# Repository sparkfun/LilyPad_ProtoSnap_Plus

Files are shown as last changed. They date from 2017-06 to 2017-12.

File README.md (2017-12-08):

SparkFun LilyPad ProtoSnap Plus
========================================

<table class="table table-hover table-striped table-bordered">
  <tr>
   <td><a href="https://www.sparkfun.com/products/14346"><div align="center">LilyPad ProtoSnap Plus</div></a></center></td>
   <td><a href="https://www.sparkfun.com/products/12922"><div align="center">LilyPad ProtoSnap Plus Kit</div></a></td>
  </tr>
  <tr>
    <td><div align="center">LilyPad ProtoSnap Plus [<a href="https://www.sparkfun.com/products/14346">DEV-14346</a> ]</div></td>
    <td><div align="center">LilyPad ProtoSnap Plus Kit [<a href="https://www.sparkfun.com/products/12922">DEV-12922</a>]</div></td>
  </tr>
</table>

Snappable prototyping board with 32u4, light sensor, buzzer, button, and leds. 

To use the ProtoSnap Plus with Arduino, install the [SparkFun Arduino_Boards](https://github.com/sparkfun/Arduino_Boards) package for avr version 1.1.7 or later.

Base examples for this board are included in the package.  Select "LilyPad USB Plus" as a board type, then see examples for that board.

For extra information on Linux use, see [/Documentation/LinuxInstallation.md](https://github.com/sparkfun/LilyPad_ProtoSnap_Plus/tree/master/Documentation/LinuxInstallation.md).

Repository Contents
-------------------

* **/Documentation** - pin mapping and design information, linux installation info.
* **/Hardware** - Eagle design files (.brd, .sch)
* **/Production** - Production panel files (.brd)

Documentation
--------------
* **[Hookup Guide](https://learn.sparkfun.com/tutorials/lilypad-protosnap-plus-hookup-guide)** - Basic hookup guide for the LilyPad ProtoSnap Plus.
* **[Activity Guide](https://learn.sparkfun.com/tutorials/lilypad-protosnap-plus-activity-guide)** - This guide will get you started with some introductory programming activities exploring each of the LilyPad pieces on the LilyPad ProtoSnap Plus. If you’ve never used Arduino to program before, this guide will walk you through the basics with example code to upload and explore.

Product Versions
----------------
* [DEV-14346](https://www.sparkfun.com/products/14346) - LilyPad ProtoSnap Plus
* [DEV-12922](https://www.sparkfun.com/products/12922) - LilyPad ProtoSnap Plus Kit Version
* [LAB-14529](https://www.sparkfun.com/products/14529) - LilyPad ProtoSnap Plus Lab Pack Version

Version History
---------------
* [V_1.0](https://github.com/sparkfun/LilyPad_ProtoSnap_Plus/tree/V_0.1) - Production release.

License Information
-------------------

This product is _**open source**_! 

Please review the LICENSE.md file for license information. 

If you have any questions or concerns on licensing, please contact techsupport@sparkfun.com.

Distributed as-is; no warranty is given.

- Your friends at SparkFun.

_<COLLABORATION CREDIT>_

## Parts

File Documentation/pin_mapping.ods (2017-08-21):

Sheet: Pin map
Physical pin | Atmel name |  | Int? | Ana IN? | I2C? | Timer? | ProMicro | Usable? | LILYPAD |  |  | Location |  | LILYPAD V0.3
 | Port | Full |  |  |  |  |  |  | Function | Pad number | Analog | Pin | Port | Function | Pad number | Analog
1 | PE6 | (INT.6/AIN0) PE6 | ??? |  |  |  | D7 |  | BG_LED3 | (19) | A0 | PE | 6 | BG_LED3 | (18)
2 |  | Uvcc |  |  |  |  | UVCC | NO
3 |  | D- |  |  |  |  | D- | NO
4 |  | D+ |  |  |  |  | D+ | NO
5 |  | Ugnd |  |  |  |  | UGND | NO
6 |  | Ucap |  |  |  |  | UCAP | NO
7 |  | Vbus |  |  |  |  | UVCC | NO
8 | PB0 | PB0,SS,PCINT0 | Y |  |  |  | TX_LED | NO | TX_LED | (15) |  | PB | 0 | TX_LED | (1)
9 | PB1 | (PCINT1/SCLK ) PB1 | Y |  |  |  | SCLK | Rather not | SCLK |  |  | PB | 1 | SCLK | [21]
10 | PB2 | (PDI/PCINT2/MOSI) PB2 | Y |  |  |  | MOSI | Rather not | MOSI |  |  | PB | 2 | MOSI | [22]
11 | PB3 | (PDO/PCINT3/MISO ) PB3 | Y |  |  |  | MISO | Rather not | MISO |  |  | PB | 3 | MISO | [23]
12 | PB7 | PCINT7/OC0A/OC1C/RTS) PB7 | Y |  |  | Y | D11# |  | LED 6 | 6 |  | PB | 7 | LED 6 | 6
13 |  | RESET |  |  |  |  | RESET | NO
14 |  | VCC |  |  |  |  | VCC | NO
15 |  | GND |  |  |  |  | GND | NO
16 |  | XTAL2 |  |  |  |  | XTAL | NO
17 |  | XTAL1 |  |  |  |  | XTAL | NO
18 | PD0 | (OC0B/SCL/INT0) PD0 |  |  | Y | Y | D3# |  | Pixel/SCL | 10 |  | PD | 0 | Pixel/SCL | 10
19 | PD1 | (SDA/INT1) PD1 |  |  | Y |  | D2 |  | SDA | 11 |  | PD | 1 | SDA | 11
20 | PD2 | (RXD1/INT2) PD2 |  |  |  |  | RXI/(D0) | Rather not | BG_LED1 | (20) |  | PD | 2 | BG_LED1 | (16)
21 | PD3 | (TXD1/INT3) PD3 |  |  |  |  | TXO(D1) | Rather not | BG_LED2 | (21) |  | PD | 3 | BG_LED2 | (17)
22 | PD5 | (XCK1/CTS) PD5 |  |  |  |  | RX_LED | NO | RX_LED | (22) |  | PD | 5 | RX_LED | (0)
23 |  | GND |  |  |  |  | GND | NO
24 |  | AVCC |  |  |  |  | VCC | NO
25 | PD4 | PD4 (ICP1/ADC8 |  | Y |  |  | D4/A6 |  | LUX in | 2 | A2 | PD | 4 | LUX in | 2 | A2
26 | PD6 | PD6 (T1/OC4D/ADC9) |  | Y |  | Y | D12/A10 |  |  | (25) | A6 | PD | 6 |  | (24) | A11
27 | PD7 | PD7 (T0/OC4D/ADC10) |  | Y |  | Y | D6#/A8 |  | LED 7 | 7 | A7 | PD | 7 | LED 7 | 7 | A7
28 | PB4 | PB4 (PCINT4/ADC11) | Y | Y |  |  | D8 |  | Button | 4 | A4 | PB | 4 | Button | 4 | A4
29 | PB5 | PB5 (PCINT5/OC1A/OC4B/ADC12 | Y | Y |  | Y | D9#/A8 |  | LED 8 | 8 | A8 | PB | 5 | LED 8 | 8 | A8
30 | PB6 | PB6 (PCINT6/OC1B/OC4B/ADC13 | Y | Y |  | Y | D10# |  | RGB_R | (12) | A1 | PB | 6 | RGB_R | (12) | A10
31 | PC6 | PC6 ( OC3A/OC4A |  |  |  | Y | D5# |  | RGB_G | (24) |  | PC | 6 | RGB_G | (13)
32 | PC7 | PC7 (ICP3/CLK0/OC4A |  |  |  | Y | D13# |  | RGB_B | (14) |  | PC | 7 | RGB_B | (14)
33 | PE2 | PE2 (HWB) |  |  |  |  | GND | NO |  | (23) |  | PE | 2 |  | (25)
34 |  | VCC |  |  |  |  | VCC | NO
35 |  | GND |  |  |  |  | GND | NO
36 | PF7 | PF7 (ADC7/TDI) |  | Y |  |  | A0 |  | Buzzer | 3 | A3 | PF | 7 | Buzzer | 3 | A3
37 | PF6 | PF6 (ADC6/TDO) |  | Y |  |  | A1 |  | empty | 9 | A9 | PF | 6 | Switch | 9 | A9
38 | PF5 | PF5 (ADC5/TMS) |  | Y |  |  | A2 |  | BG_LED0 | (13) | A5 | PF | 5 | BG_LED0 | (15) | A6
39 | PF4 | PF4 (ADC4/TCK) |  | Y |  |  | A3 |  | LED 5 | 5 | A10 | PF | 4 | LED 5 | 5 | A5
40 | PF1 | PF1 (ADC1) |  | Y |  |  | A4 |  | BG_LED4 | (1) | A11 | PF | 1 | BG_LED4 | (19) | A1
41 | PF0 | PF0 (ADC0) |  | Y |  |  | A5 |  | BG_LED5 | (0) |  | PF | 0 | BG_LED5 | (20) | A0
42 |  | AREF |  |  |  |  | AREF | NO
43 |  | GND |  |  |  |  | GND | NO
44 |  | AVCC |  |  |  |  | VCC | NO

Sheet: Required pins
Name | Required function | Priority | Notes
Lux sen | analog | high
buzzer |  | high
Btn |  | high
LED Y | PWM | high
LED R | PWM | high
LED G | PWM | high
LED B | PWM | high
Pixel | PWM | high
RGB R | PWM | mid
RGB G | PWM | mid
RGB B | PWM | mid
Led 1 |  | low
Led 2 |  | low
Led 3 |  | low
Led 4 |  | low

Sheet: circlemath
 | Circle | Wedges | Degrees
 | 360 | 15 | 24
 | Start:
 | Offset | 180 |  |  | Calculate position
 | Direction: | -1 |  |  | Radius: | 0.8661
 | At | Angle | Angle |  | X | Y
 | 0 | 180 | 180
 | 24 | 156 | 156
 | 48 | 132 | 132
 | 72 | 108 | 108
 | 96 | 84 | 84
 | 120 | 60 | 60
 | 144 | 36 | 36
 | 168 | 12 | 12
 | 192 | -12 | -12
 | 216 | -36 | -36
 | 240 | -60 | -60
 | 264 | -84 | -84
 | 288 | 252 | 252
 | 312 | 588 | 588
 | 336 | 924 | 924
 | 1. Locate centers: |  |  | 2. Calc coords | Radius: | 0.8661 | Calc rotation | Start angle: | 90
 | top as 0 deg | Rt as 0 deg |  |  | X | Y |  | Rot dir: | -1
USB | 0 | 90 |  |  | 0.0000 | 0.8661 |  | -90
PWR | 24 | 114 |  |  | -0.3523 | 0.7913 |  | -66
2 | 48 | 138 |  |  | -0.6437 | 0.5796 |  | -42
3 | 72 | 162 |  |  | -0.8237 | 0.2677 |  | -18
GND | 96 | 186 |  |  | -0.8614 | -0.0905 |  | 6
4 | 120 | 210 |  |  | -0.7501 | -0.4331 |  | 30
5 | 144 | 234 |  |  | -0.5091 | -0.7007 |  | 54
6 | 168 | 258 |  |  | -0.1801 | -0.8472 |  | 78
7 | 192 | 282 |  |  | 0.1801 | -0.8472 |  | 102
8 | 216 | 306 |  |  | 0.5091 | -0.7007 |  | 126
9 | 240 | 330 |  |  | 0.7501 | -0.4331 |  | 150
PWR | 264 | 354 |  |  | 0.8614 | -0.0905 |  | 174
10 | 288 | 18 |  |  | 0.8237 | 0.2677 |  | 198
11 | 312 | 42 |  |  | 0.6437 | 0.5796 |  | 222
GND | 336 | 66 |  |  | 0.3523 | 0.7913 |  | 246

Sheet: v03
Location |  | LILYPAD V0.3 (By schematic) |  |  | LILYPAD V0.3 (Correct – update sch)
Pin | Port | Function | Pad number | Analog | Function | Pad number | Analog
PE | 6 | BG_LED3 | (18) | A1 | BG_LED0 | (15)
PB | 0 | TX_LED/SS | (1) |  | TX_LED/SS | (1)
PB | 1 | SCLK | [21] |  | SCLK | [21]
PB | 2 | MOSI | [22] |  | MOSI | [22]
PB | 3 | MISO | [23] |  | MISO | [23]
PB | 7 | LED 6 | 6 |  | LED 6 | 6
PD | 0 | Pixel/SCL | 10 |  | Pixel/SCL | 10
PD | 1 | SDA | 11 |  | SDA | 11
PD | 2 | BG_LED1 | (16) |  | BG_LED5 | (20)
PD | 3 | BG_LED2 | (17) |  | BG_LED4 | (19)
PD | 5 | RX_LED | (0) |  | RX_LED | (0)
PD | 4 | LUX in | 2 | A2 | LUX in | 2 | A2
PD | 6 |  | (24) | A12 |  | (24) | A11
PD | 7 | LED 7 | 7 | A7 | LED 7 | 7 | A7
PB | 4 | Button | 4 | A4 | Button | 4 | A4
PB | 5 | LED 8 | 8 | A8 | LED 8 | 8 | A8
PB | 6 | RGB_R | (12) | A11 | RGB_R | (12) | A10
PC | 6 | RGB_G | (13) |  | RGB_G | (13)
PC | 7 | RGB_B | (14) |  | RGB_B | (14)
PE | 2 |  | (25) |  |  | (25)
PF | 7 | Buzzer | 3 | A3 | Buzzer | 3 | A3
PF | 6 | Switch | 9 | A9 | Switch | 9 | A9
PF | 5 | BG_LED0 | (15) | A0 | BG_LED3 | (18) | A6
PF | 4 | LED 5 | 5 | A5 | LED 5 | 5 | A5
PF | 1 | BG_LED4 | (19) | A6 | BG_LED2 | (17) | A1
PF | 0 | BG_LED5 | (20) | A10 | BG_LED1 | (16) | A0

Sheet: CheatSheet
 | Arduino Pin Name
Function | Digital | Analog
RX_LED | (0)
TX_LED/SS | (1)
LUX in | 2 | A2
Buzzer | 3 | A3
Button | 4 | A4
LED 5 | 5 | A5
LED 6 | 6
LED 7 | 7 | A7
LED 8 | 8 | A8
Switch | 9 | A9
Pixel/SCL | 10
SDA | 11
RGB_R | (12) | (A10)
RGB_G | (13)
RGB_B | (14)
BG_LED0 | (15)
BG_LED1 | (16) | (A0)
BG_LED2 | (17) | (A1)
BG_LED3 | (18) | (A6)
BG_LED4 | (19)
BG_LED5 | (20)
SCLK | [21]
MOSI | [22]
MISO | [23]
 | (24) | (A11)
 | (25)
Key:
Physical petal: | n
Exposed via: | [n]
Internal only: | (n)

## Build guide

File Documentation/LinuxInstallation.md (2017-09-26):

Tested on Ubuntu 14.04

To get uploads working, you'll need to add a udev rule and set permissions correctly.

**udev Rules**

Make a new file called:

`/etc/udev/rules.d/77-arduino.rules`

In it, enter the following and save:

`ATTRS{idVendor}=="1b4f", MODE="0660", GROUP="dialout", ENV{ID_MM_DEVICE_IGNORE}="1"`

Then, restart the rules with:

`run sudo udevadm control --reload-rules`

**Permissions**

If you've successfully set your udev rules, running Arduino as root should allow uploads.  Rather then run as root all the time, make sure the user and the usb device are both in the `dialout` group.

To see what the device is comming up as, enter:

`ls -l /dev/ttyACM*`

which will list *all* ttyACM devices.  With only the LilyPad USB Plus plugged in, this should read something like:

`crw-rw---- 1 root dialout 166, 0 Sep 26 11:05 /dev/ttyACM0`

showing that the udev rule worked making the usb device `dialout`.

Use:

`groups`

to list the groups the current user is part of.  If `dialout` is not one of them, enter:

`sudo adduser username dialout`

where `username` is your user account.

Afterwards, log out and back in again and Arduino should be able to upload without running as root.

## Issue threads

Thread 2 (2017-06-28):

Break-away holes too close

marshalltaylorSFE, 2017-06-28:
Move away from trace, expand bridge slightly

Closed 2017-10-06.

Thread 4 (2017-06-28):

Fix unused pin names

marshalltaylorSFE, 2017-06-28:
Re-name nets that have no connection to match pin mux matrix (also, include pin mux matrix in docs)

Closed 2017-10-06.

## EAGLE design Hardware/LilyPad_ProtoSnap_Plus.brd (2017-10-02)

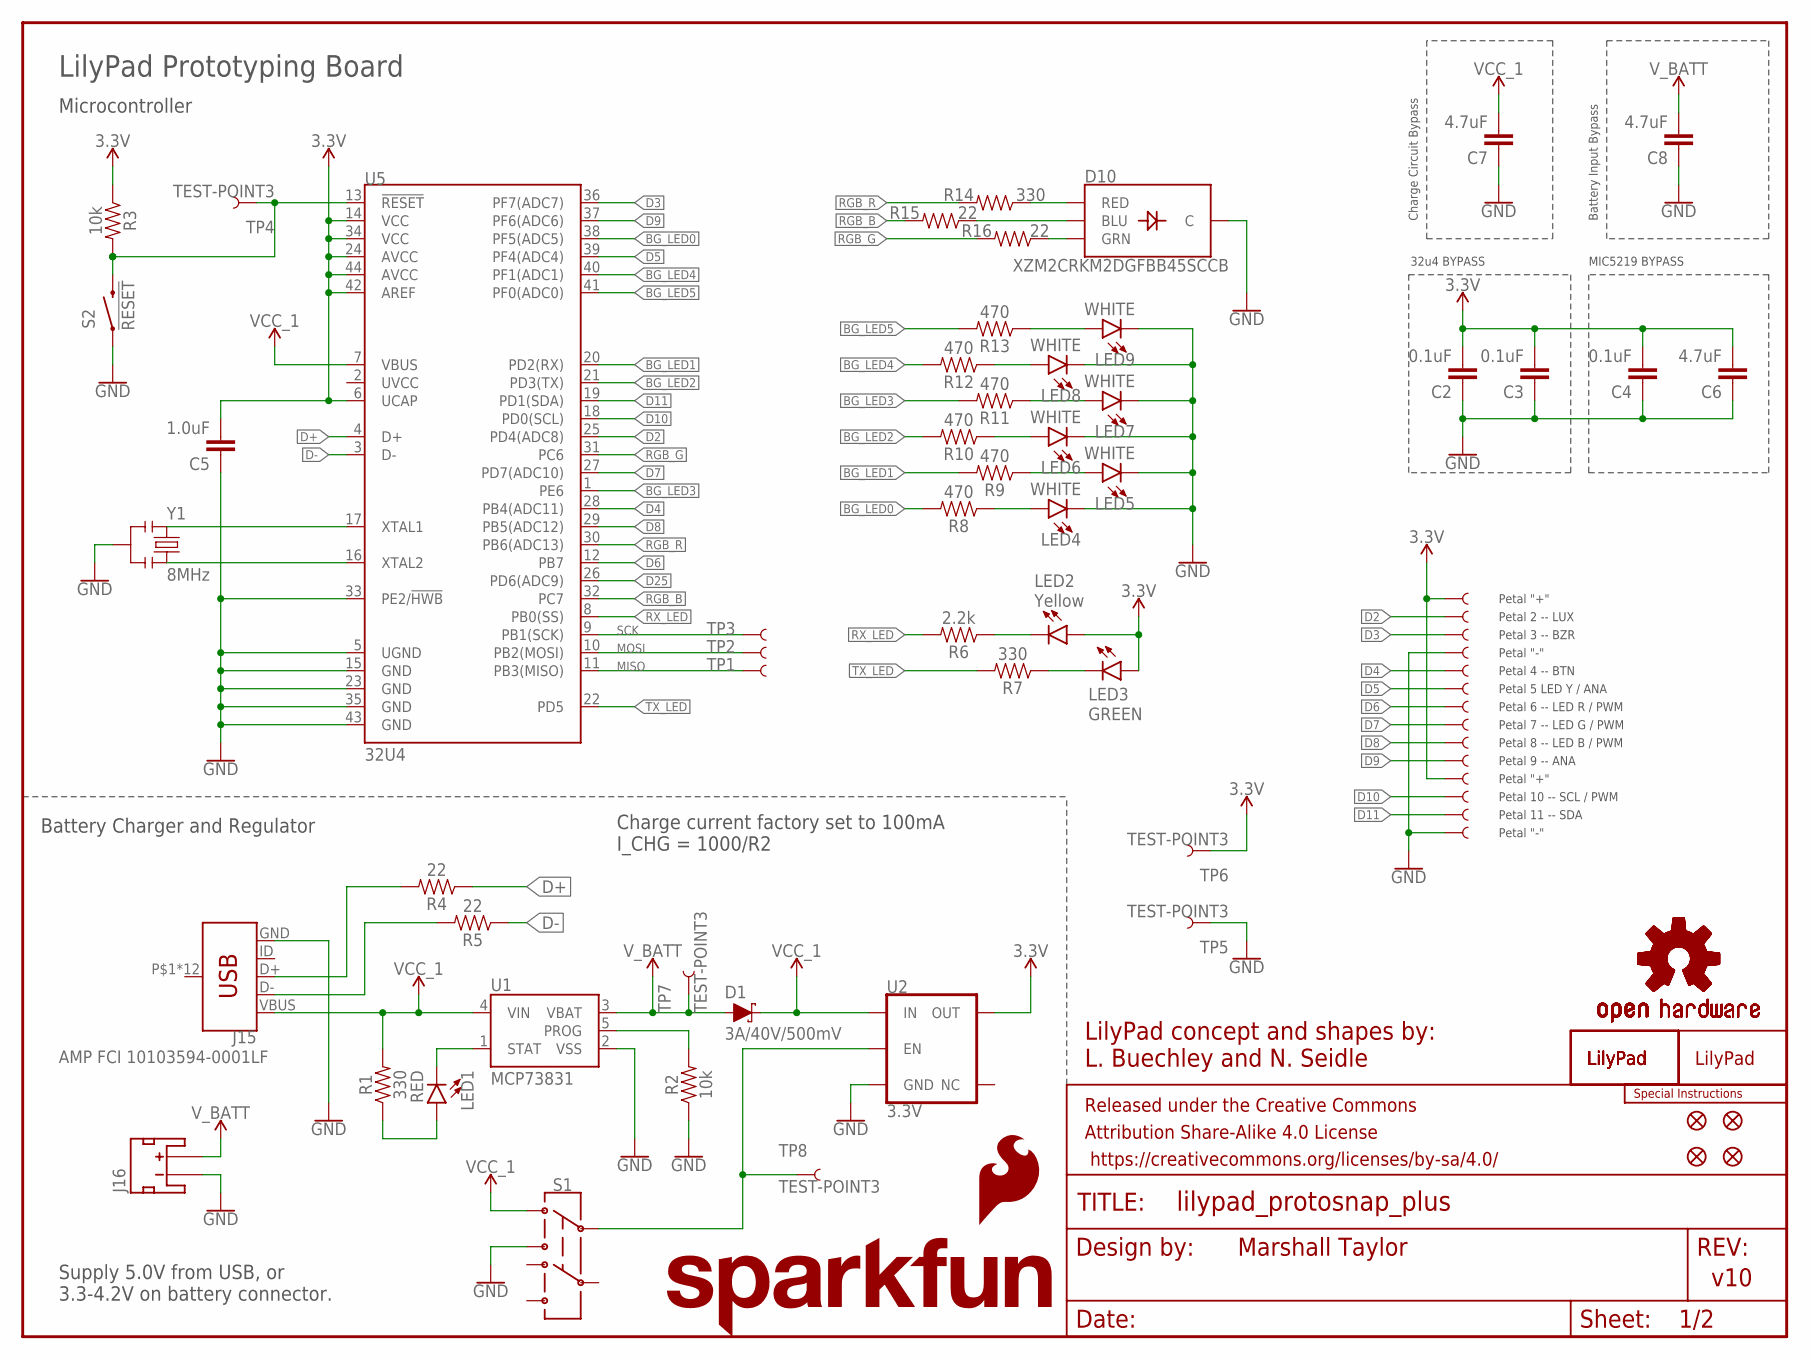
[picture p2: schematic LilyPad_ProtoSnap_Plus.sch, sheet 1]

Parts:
C2, C3, C4: 0.1uF; 0402
C5: 1.0uF; 0402
C6, C7, C8: 4.7uF; 0603
D1: 3A/40V/500mV; SMA-DIODE
D10: XZM2CRKM2DGFBB45SCCB; PLCC4SMDLED
FRAME1: FRAME-LETTER; CREATIVE_COMMONS
J1, J2, J3, J4, J5, J6, J7, J8, J9, J10, J11, J12, J13, J14: SEWTAP_LONG-2SIDE; PETAL-LONG-1-2SIDE
J15: AMP FCI 10103594-0001LF; USB-MICROB-PTH
J16: JST_2MM_MALE; JST-2-SMD
JP2, JP3, JP11, JP14: FIDUCIALUFIDUCIAL; MICRO-FIDUCIAL
LED1: RED; LED-0603
LED2: Yellow; LED-0603
LED3: GREEN; LED-0603
LED4, LED5, LED6, LED7, LED8, LED9: WHITE; LED-0603
LOGO1: SFE_LOGO_NAME.1_INCH; SFE_LOGO_NAME_.1
LOGO2: SFE_LOGO_FLAME.1EXP; SFE_LOGO_FLAME_COPPER_EXPOSED_.1
LOGO4, LOGO5, LOGO6: OSHW-LOGOS; OSHW-LOGO-S
R1, R7, R14: 330; 0603
R2, R3: 10k; 0603
R4, R5, R15, R16: 22; 0402
R6: 2.2k; 0603
R8, R9, R10, R11, R12, R13: 470; 0402
S1: SWITCH-DPDT-SMD-AYZ0202; SWITCH_DPDT_SMD_AYZ0202
S2: !RESET; TACTILE_SWITCH_SMD_5.2MM
TP1, TP2, TP3, TP4, TP5, TP6, TP7, TP8: TEST-POINT3; PAD.03X.03
U1: MCP73831; SOT23-5
U2: 3.3V; SOT23-5
U5: 32U4; QFN-44-PAD_1:1-LESS_PASTE
U$1, U$13, U$43: LILYLOGO_SHORT; LILYPAD-WEARABLES_LOGO-LILYPAD
U$44: SPECIAL_INSTRUCTIONS-ORDERING; ORDERING_INSTRUCTIONS
U$73: LILYLOGO_ABR; LILYPAD-WEARABLES_LOGO-L
Y1: 8MHz; RESONATOR-SMD

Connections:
3.3V: C2.2, C3.2, C4.2, C5.2, C6.2, J1.1, J11.1, LED2.A, LED3.A, R3.1, TP6.P$1, U2.5 (OUT), U5.6 (UCAP), U5.14 (VCC), U5.24 (AVCC), U5.34 (VCC), U5.42 (AREF), U5.44 (AVCC); also elsewhere on the board
BG_LED0: R8.2, U5.38 (PF5(ADC5))
BG_LED1: R9.2, U5.20 (PD2(RX))
BG_LED2: R10.2, U5.21 (PD3(TX))
BG_LED3: R11.2, U5.1 (PE6)
BG_LED4: R12.2, U5.40 (PF1(ADC1))
BG_LED5: R13.2, U5.41 (PF0(ADC0))
D2: J2.1, U5.25 (PD4(ADC8)); also elsewhere on the board
D3: J3.1, U5.36 (PF7(ADC7)); also elsewhere on the board
D4: J5.1, U5.28 (PB4(ADC11)); also elsewhere on the board
D5: J6.1, U5.39 (PF4(ADC4)); also elsewhere on the board
D6: J7.1, U5.12 (PB7); also elsewhere on the board
D7: J8.1, U5.27 (PD7(ADC10)); also elsewhere on the board
D8: J9.1, U5.29 (PB5(ADC12)); also elsewhere on the board
D9: J10.1, U5.37 (PF6(ADC6)); also elsewhere on the board
D10: J12.1, U5.18 (PD0(SCL)); also elsewhere on the board
D11: J13.1, U5.19 (PD1(SDA)); also elsewhere on the board
D25: U5.26 (PD6(ADC9))
D+: R4.1, U5.4 (D+)
D-: R5.1, U5.3 (D-)
GND: C2.1, C3.1, C4.1, C5.1, C6.1, C7.1, C8.1, D10.4 (C), J4.1, J14.1, J15.GND, J16.1 (-), LED4.C, LED5.C, LED6.C, LED7.C, LED8.C, LED9.C, R2.1, S1.3, S2.1, S2.2 (1), TP5.P$1, U1.2 (VSS), U2.2 (GND), U5.5 (UGND), U5.15 (GND), U5.23 (GND), U5.33 (PE2/!HWB), U5.35 (GND), U5.43 (GND), Y1.2; also elsewhere on the board
MISO: TP1.P$1, U5.11 (PB3(MISO))
MOSI: TP2.P$1, U5.10 (PB2(MOSI))
unnamed: LED2.C, R6.1
unnamed: S1.2, TP8.P$1, U2.3 (EN)
unnamed: LED1.A, R1.1
unnamed: LED1.C, U1.1 (STAT)
unnamed: U5.17 (XTAL1), Y1.1
unnamed: R2.2, U1.5 (PROG)
unnamed: U5.16 (XTAL2), Y1.3
unnamed: D10.2 (GRN), R16.1
unnamed: LED7.A, R11.1
unnamed: LED6.A, R10.1
unnamed: LED5.A, R9.1
unnamed: LED8.A, R12.1
unnamed: LED9.A, R13.1
unnamed: D10.3 (BLU), R15.1
unnamed: D10.1 (RED), R14.1
unnamed: LED4.A, R8.1
unnamed: J15.D-, R5.2
unnamed: J15.D+, R4.2
unnamed: LED3.C, R7.1
RESET: R3.2, S2.3 (2), S2.4 (2), TP4.P$1, U5.13 (!RESET)
RGB_B: R15.2, U5.32 (PC7)
RGB_G: R16.2, U5.31 (PC6)
RGB_R: R14.2, U5.30 (PB6(ADC13))
RX_LED: R6.2, U5.8 (PB0(SS))
SCK: TP3.P$1, U5.9 (PB1(SCK))
TX_LED: R7.2, U5.22 (PD5)
VCC_1: C7.2, D1.C, J15.VBUS, R1.2, S1.1, U1.4 (VIN), U2.1 (IN), U5.7 (VBUS)
V_BATT: C8.2, D1.A, J16.2 (+), TP7.P$1, U1.3 (VBAT)

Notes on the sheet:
32u4 BYPASS
MIC5219 BYPASS
Marshall Taylor
v10
LilyPad concept and shapes by: L. Buechley and N. Seidle
Charge Circuit Bypass
Battery Input Bypass
Petal 2 -- LUX
Petal 3 -- BZR
Petal 4 -- BTN
Petal 5 LED Y / ANA
Petal 6 -- LED R / PWM
Petal 7 -- LED G / PWM
Petal 8 -- LED B / PWM
Petal 9 -- ANA
Petal 10 -- SCL / PWM
Petal 11 -- SDA
Petal "+"
Petal "-"
LilyPad Prototyping Board
Microcontroller
Battery Charger and Regulator
Charge current factory set to 100mA I_CHG = 1000/R2
Supply 5.0V from USB, or 3.3-4.2V on battery connector.

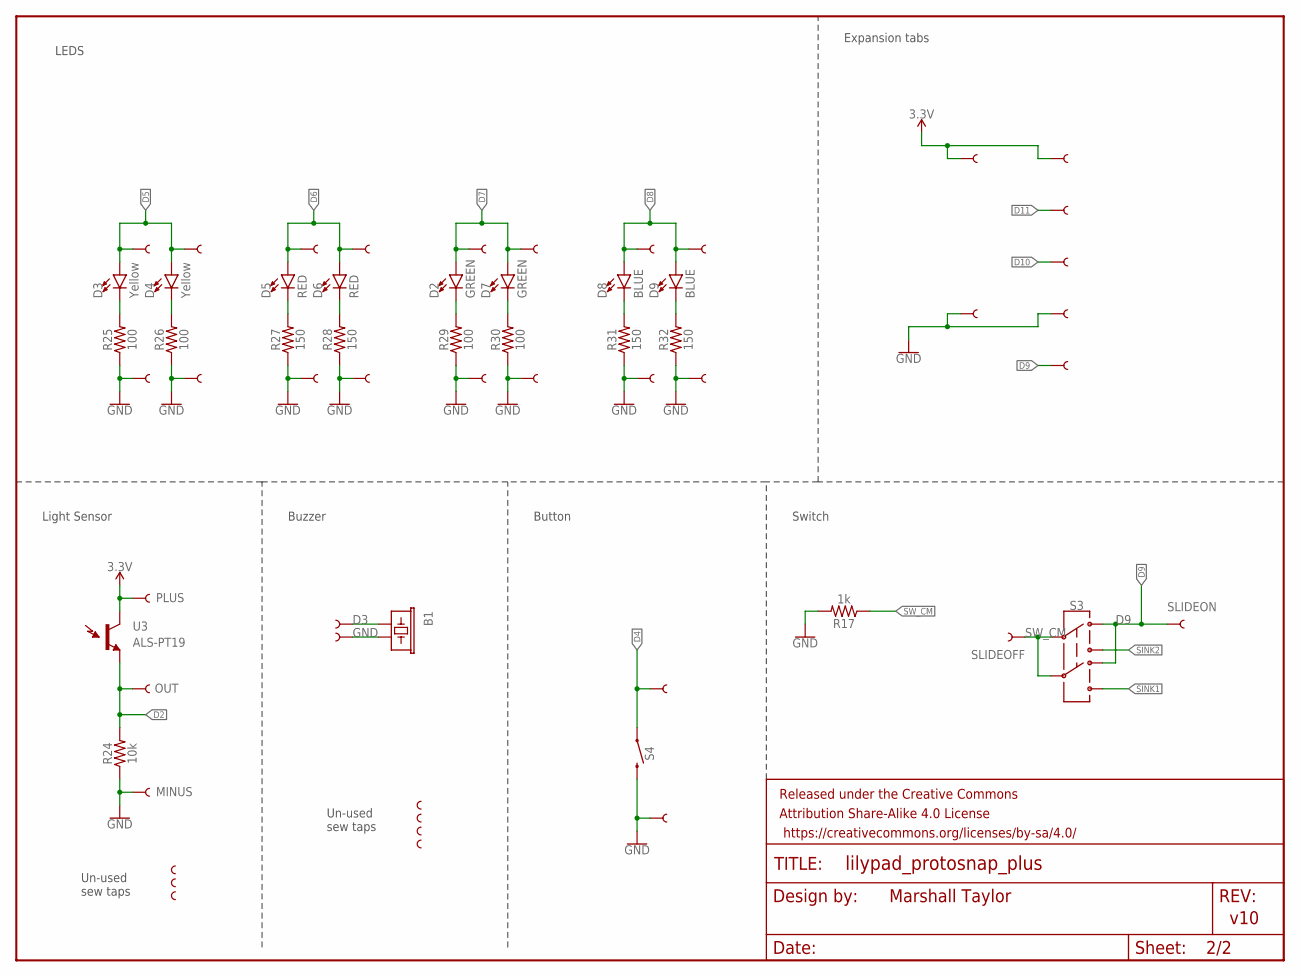
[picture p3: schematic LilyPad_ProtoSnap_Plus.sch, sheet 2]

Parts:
B1: Buzzer; BUZZER-CCV
D2, D7: GREEN; LED-1206
D3, D4: Yellow; LED-1206
D5, D6: RED; LED-1206
D8, D9: BLUE; LED-1206
FRAME2: FRAME-LETTERNO_PACKAGE; DUMMY
JP1, JP4, JP5, JP6, JP7, JP8, JP9, JP10, JP20, JP21, JP22, JP23, JP24, JP25, JP26, JP27: SEWTAP_SMALL-2SIDE; PETAL-SMALL-2SIDE
JP12, JP13: SEWTAP_MEDIUM-2SIDE; PETAL-MEDIUM-2SIDE
R17: 1k; 0603
R24: 10k; 0603
R25, R26, R29, R30: 100; 0603
R27, R28, R31, R32: 150; 0603
S3: SWITCH-DPDT-SMD-AYZ0202; SWITCH_DPDT_SMD_AYZ0202
S4: MOMENTARY-SWITCH-SPST-SMD-5.2-REDUNDANT; TACTILE_SWITCH_SMD_5.2MM
SEWTAPLS+: PLUS; PETAL-SMALL-2SIDE
SEWTAPLS-: MINUS; PETAL-SMALL-2SIDE
SEWTAPLSOUT: OUT; PETAL-SMALL-2SIDE
SLIDEOFF: SEWTAP_MEDIUM-2SIDE; PETAL-MEDIUM-2SIDE
SLIDEON: SEWTAP_MEDIUM-2SIDE; PETAL-MEDIUM-2SIDE
ST1, ST2, ST3: SEWTAP-NOHOLE_SM_NH; PETAL-SMALL-NOHOLE
U3: ALS-PT19
U$35, U$36, U$37, U$40: SEWTAP-NOHOLE_SM_NH; PETAL-SMALL-NOHOLE
U$38, U$39: SEWTAP_SMALL-2SIDE; PETAL-SMALL-2SIDE
U$41, U$42, U$51/SDA, U$52/SCL, U$52/SCL1, U$53, U$54: GATOR_HOLE_PAIR; GATOR_HOLES

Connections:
3.3V: SEWTAPLS+.1, U3.C (C1), U$41.P$1, U$41.P$2, U$42.P$1, U$42.P$2; also elsewhere on the board
D2: R24.2, SEWTAPLSOUT.1, U3.E (E1); also elsewhere on the board
D3: B1.+ (1), U$39.1; also elsewhere on the board
D4: JP12.1, S4.1, S4.2 (1); also elsewhere on the board
D5: D3.A, D4.A, JP20.1, JP22.1; also elsewhere on the board
D6: D5.A, D6.A, JP24.1, JP26.1; also elsewhere on the board
D7: D2.A, D7.A, JP7.1, JP8.1; also elsewhere on the board
D8: D8.A, D9.A, JP9.1, JP10.1; also elsewhere on the board
D9: S3.1, S3.4, SLIDEON.1, U$52/SCL1.P$1, U$52/SCL1.P$2; also elsewhere on the board
D10: U$52/SCL.P$1, U$52/SCL.P$2; also elsewhere on the board
D11: U$51/SDA.P$1, U$51/SDA.P$2; also elsewhere on the board
GND: B1.- (2), JP1.1, JP4.1, JP5.1, JP6.1, JP13.1, JP21.1, JP23.1, JP25.1, JP27.1, R17.2, R24.1, R25.1, R26.1, R27.1, R28.1, R29.1, R30.1, R31.1, R32.1, S4.3 (2), S4.4 (2), SEWTAPLS-.1, U$38.1, U$53.P$1, U$53.P$2, U$54.P$1, U$54.P$2; also elsewhere on the board
unnamed: D3.C, R25.2
unnamed: D4.C, R26.2
unnamed: D5.C, R27.2
unnamed: D6.C, R28.2
SINK1: S3.6
SINK2: S3.3
SW_CM: R17.1, S3.2, S3.5, SLIDEOFF.1
X003: D2.C, R29.2
X004: D7.C, R30.2
X005: D8.C, R31.2
X006: D9.C, R32.2

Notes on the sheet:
Un-used sew taps
Light Sensor
Button
LEDS
Expansion tabs
Buzzer
Marshall Taylor
v10
Switch

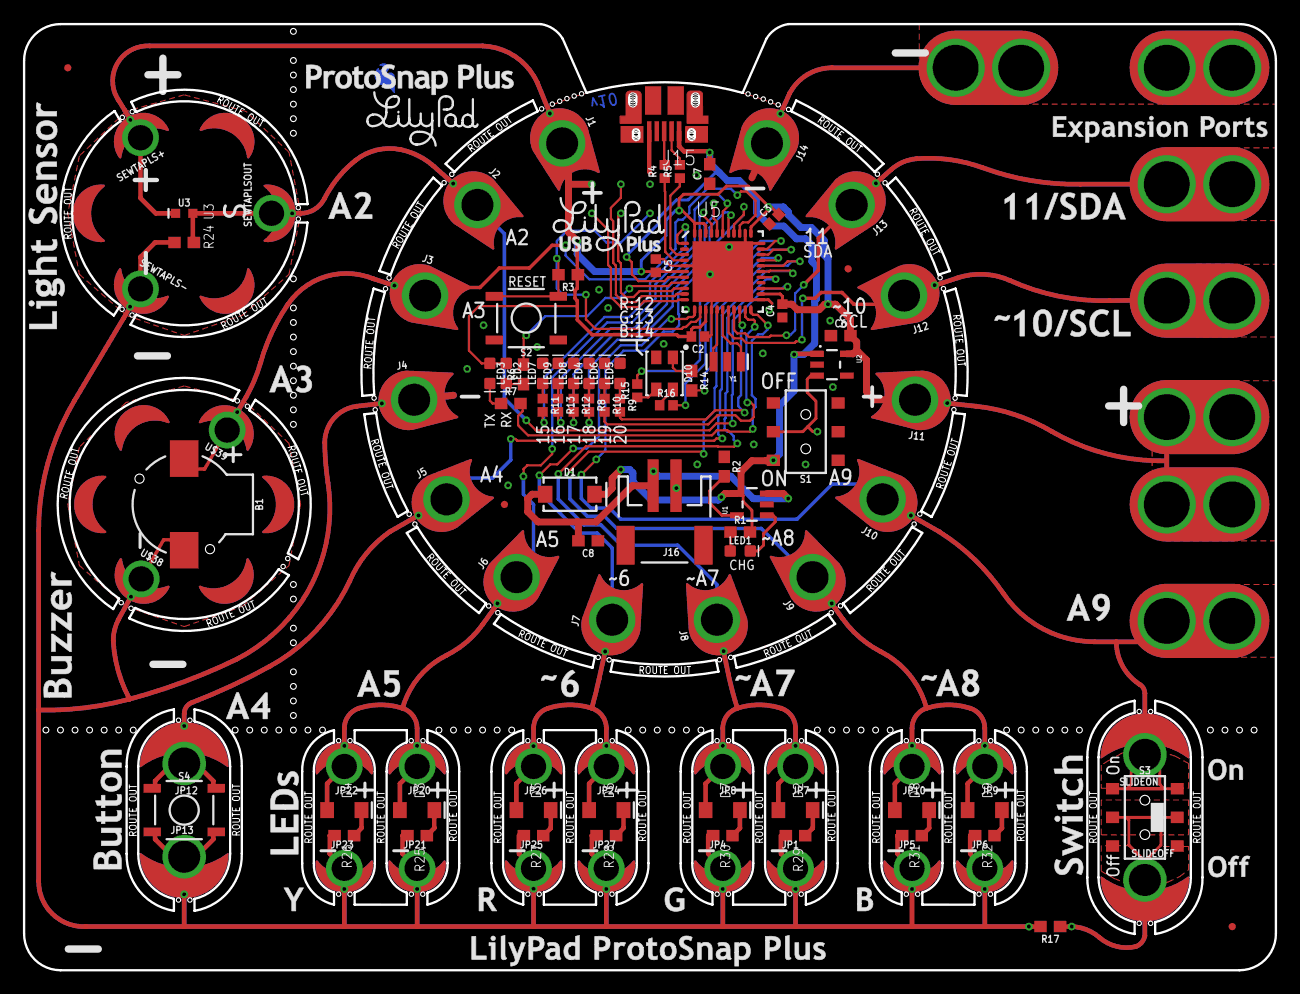
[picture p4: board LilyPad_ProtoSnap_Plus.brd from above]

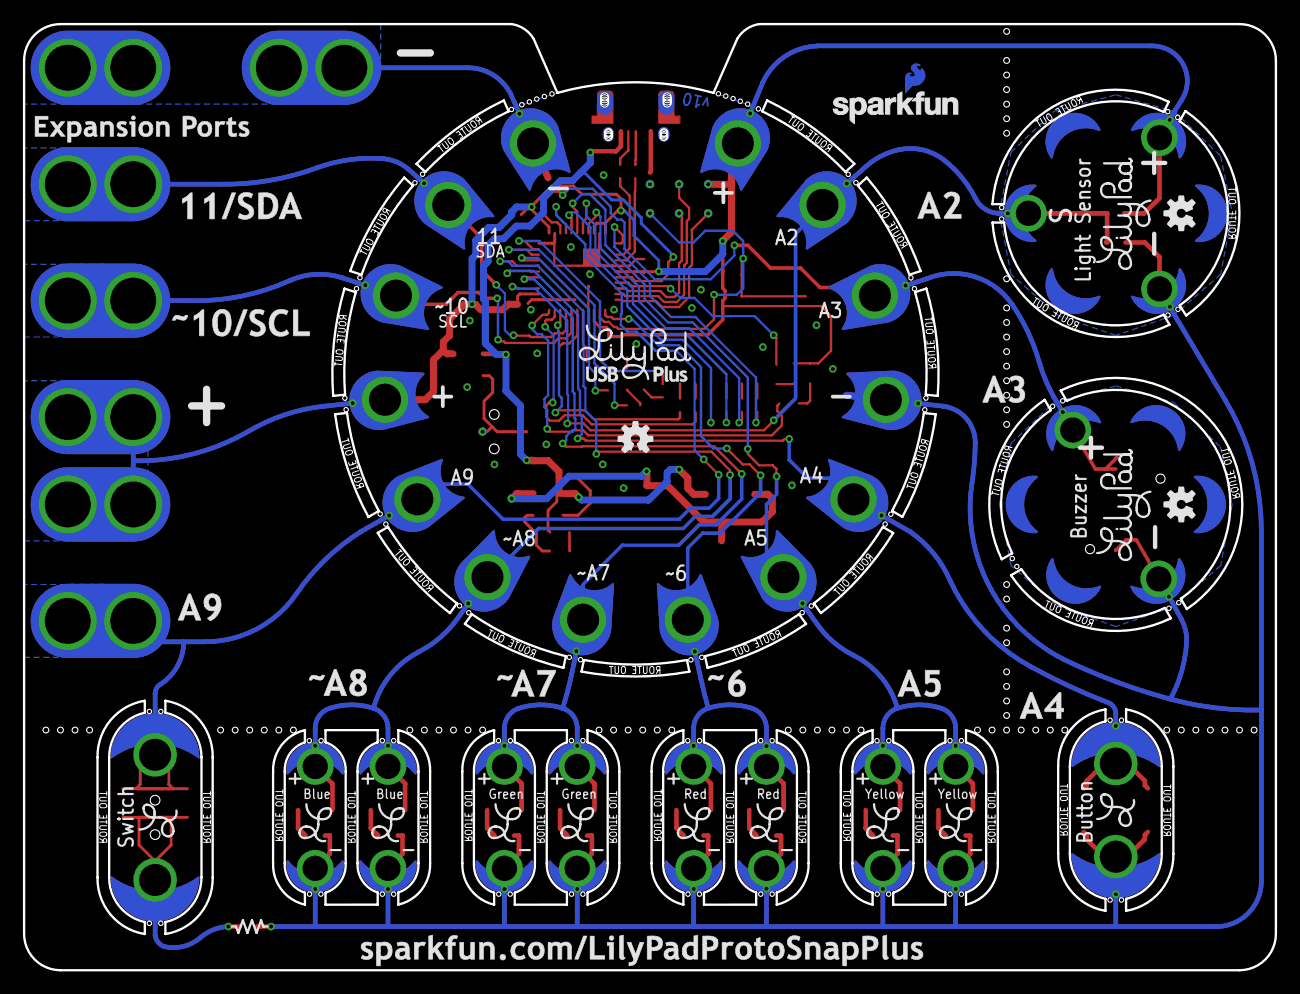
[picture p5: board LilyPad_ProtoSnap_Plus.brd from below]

Board: 2 copper layers, 109.2 x 82.5 mm, 197 parts (26 on the bottom side), 59 nets.

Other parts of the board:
L001, L002, L003, L004: LOGO-L
U$3, U$9, U$11, U$15, U$17, U$19, U$21, U$23, U$25, U$27, U$29, U$31, U$33, U$34: PETAL_PAD_OFF
U$5, U$6: LILYLOGO_SHORT; LILYPAD-WEARABLES_LOGO-LILYPAD
U$7, U$8, U$10, U$12, U$16, U$18, U$20, U$22, U$24, U$26, U$28, U$30, U$32: PETAL_SPACE_OFF
U$45, U$46, U$48, U$49, U$50: LOGO-L
U$51, U$52, U$55, U$56, U$57, U$58, U$59, U$60, U$61, U$62, U$63, U$64, U$65, U$66, U$67, U$68, U$70, U$71: ROUTE_TICKS

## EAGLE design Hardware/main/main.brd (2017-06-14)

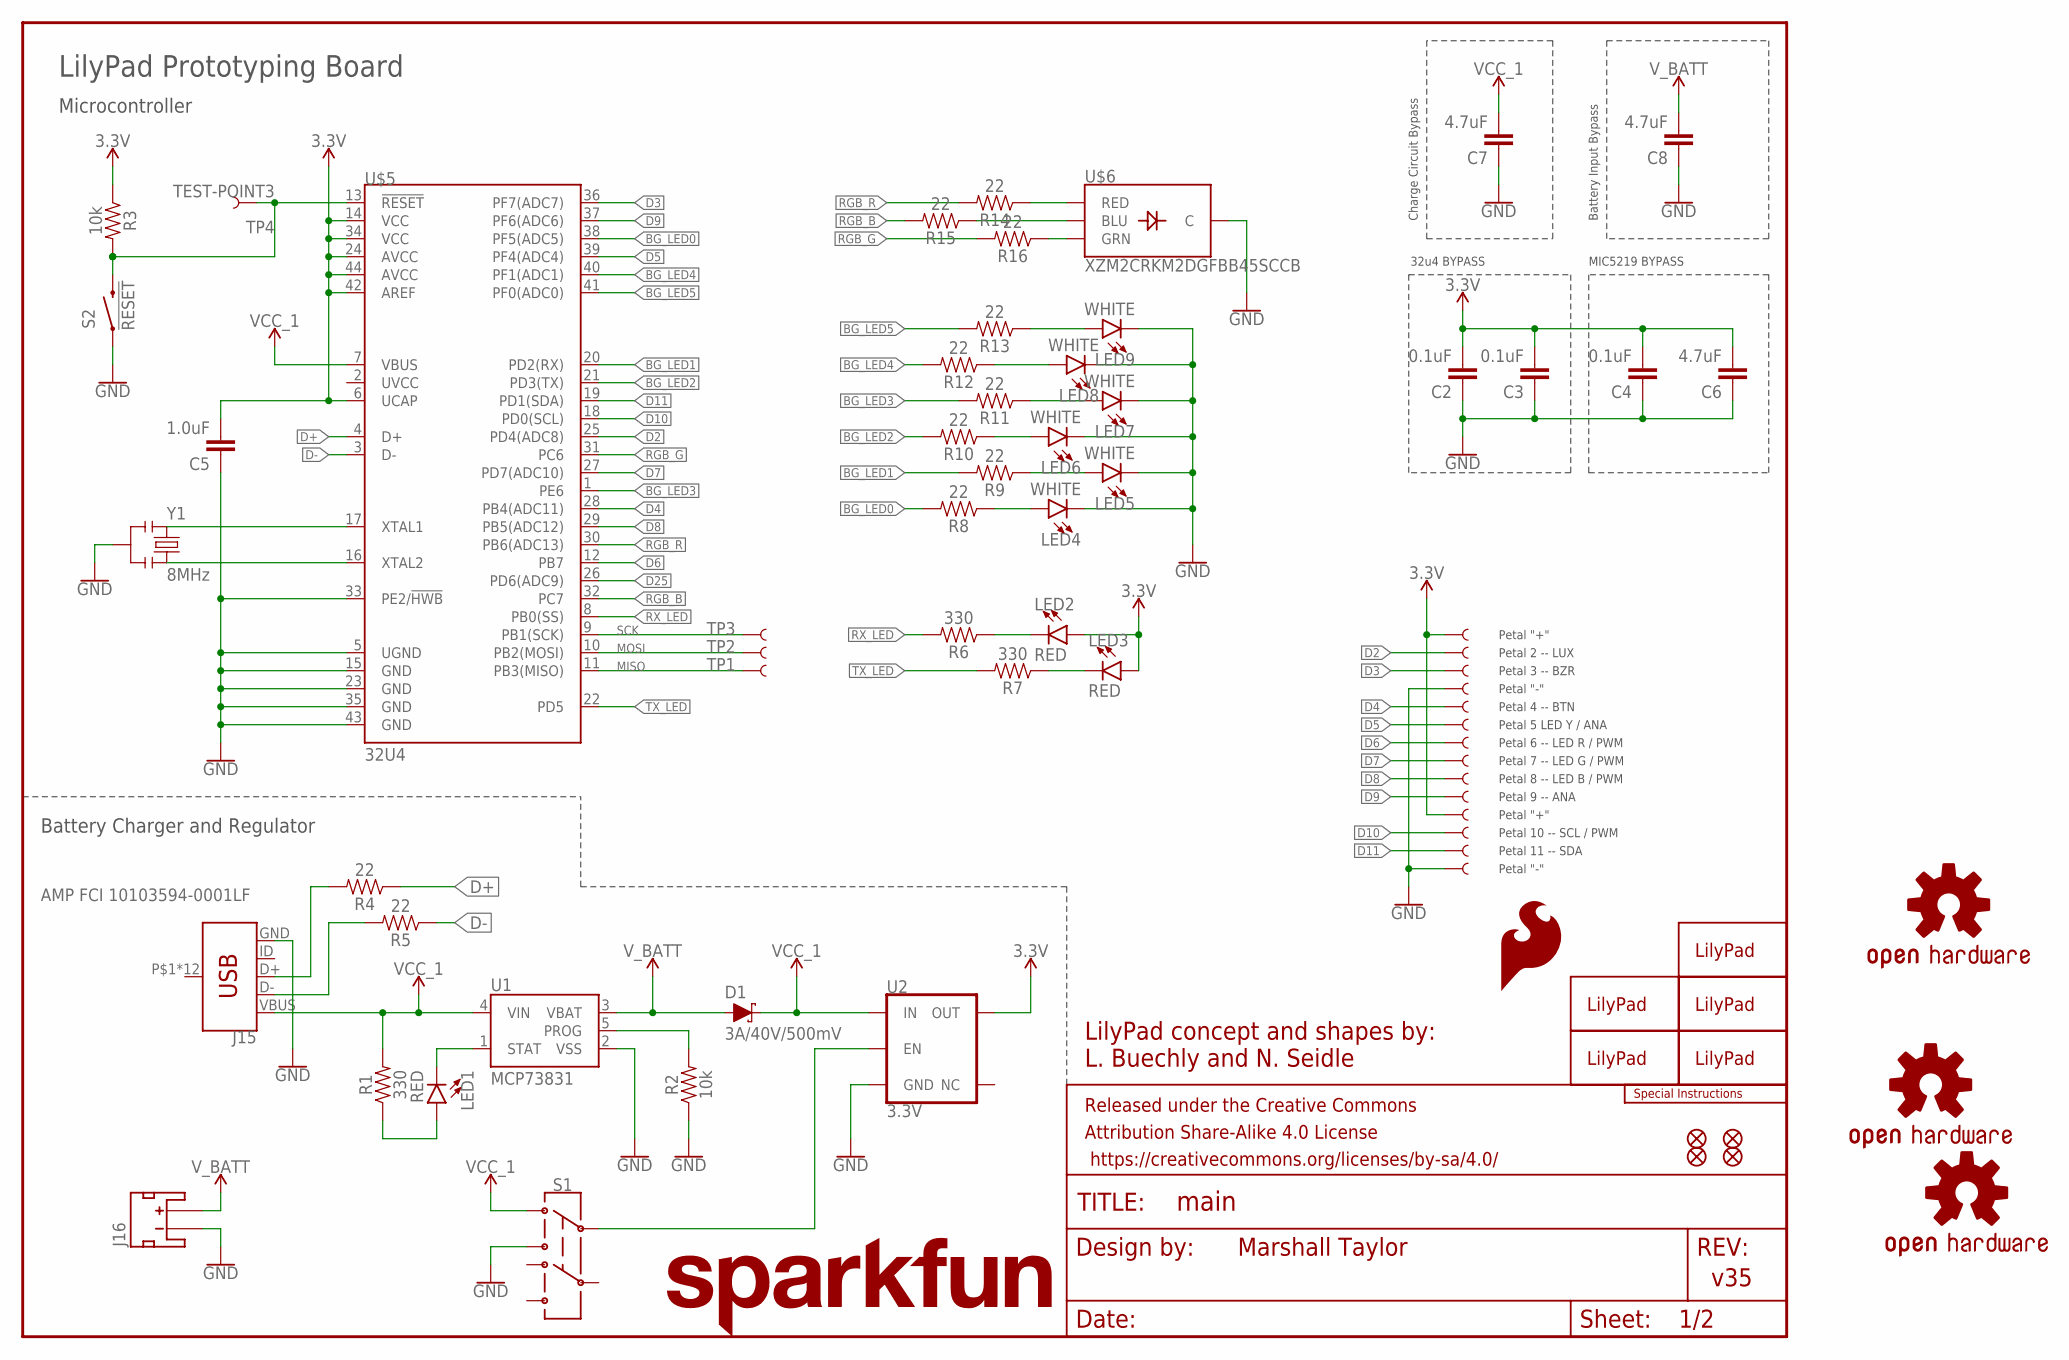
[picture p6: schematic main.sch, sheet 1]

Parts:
C2, C3, C4: 0.1uF; 0402
C5: 1.0uF; 0402
C6, C7, C8: 4.7uF; 0603
D1: 3A/40V/500mV; SMA-DIODE
FRAME1: FRAME-LETTER; CREATIVE_COMMONS
J1, J2, J3, J4, J5, J6, J7, J8, J9, J10, J11, J12, J13, J14: SEWTAP_LONG; PETAL-LONG-1
J15: AMP FCI 10103594-0001LF; USB-MICROB-PTH
J16: JST_2MM_MALE; JST-2-SMD
JP2, JP3, JP11, JP14: FIDUCIALUFIDUCIAL; MICRO-FIDUCIAL
LED1, LED2, LED3: RED; LED-0603
LED4, LED5, LED6, LED7, LED8, LED9: WHITE; LED-0603
LOGO1: SFE_LOGO_NAME.1_INCH; SFE_LOGO_NAME_.1
LOGO2: SFE_LOGO_FLAME.1EXP; SFE_LOGO_FLAME_COPPER_EXPOSED_.1
LOGO4, LOGO5, LOGO6: OSHW-LOGOS; OSHW-LOGO-S
R1, R6, R7: 330; 0603
R2, R3: 10k; 0603
R4, R5, R8, R9, R10, R11, R12, R13, R14, R15, R16: 22; 0402
S1: SWITCH-DPDT-SMD-AYZ0202; SWITCH_DPDT_SMD_AYZ0202
S2: !RESET; TACTILE_SWITCH_SMD_5.2MM
TP1, TP2, TP3, TP4: TEST-POINT3; PAD.03X.03
U1: MCP73831; SOT23-5
U2: 3.3V; SOT23-5
U$1, U$13: LILYLOGO_SHORT; LILYPAD-WEARABLES_LOGO-LILYPAD
U$5: 32U4; QFN-44
U$6: XZM2CRKM2DGFBB45SCCB; PLCC4SMDLED
U$43, U$72, U$73: LILYLOGO_ABR; LILYPAD-WEARABLES_LOGO-L
U$44: SPECIAL_INSTRUCTIONS-ORDERING; ORDERING_INSTRUCTIONS
Y1: 8MHz; RESONATOR-SMD

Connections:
3.3V: C2.2, C3.2, C4.2, C5.2, C6.2, J1.1, J11.1, LED2.A, LED3.A, R3.1, U2.5 (OUT), U$5.6 (UCAP), U$5.14 (VCC), U$5.24 (AVCC), U$5.34 (VCC), U$5.42 (AREF), U$5.44 (AVCC); also elsewhere on the board
BG_LED0: R8.2, U$5.38 (PF5(ADC5))
BG_LED1: R9.2, U$5.20 (PD2(RX))
BG_LED2: R10.2, U$5.21 (PD3(TX))
BG_LED3: R11.2, U$5.1 (PE6)
BG_LED4: R12.2, U$5.40 (PF1(ADC1))
BG_LED5: R13.2, U$5.41 (PF0(ADC0))
D2: J2.1, U$5.25 (PD4(ADC8)); also elsewhere on the board
D3: J3.1, U$5.36 (PF7(ADC7)); also elsewhere on the board
D4: J5.1, U$5.28 (PB4(ADC11)); also elsewhere on the board
D5: J6.1, U$5.39 (PF4(ADC4)); also elsewhere on the board
D6: J7.1, U$5.12 (PB7); also elsewhere on the board
D7: J8.1, U$5.27 (PD7(ADC10)); also elsewhere on the board
D8: J9.1, U$5.29 (PB5(ADC12)); also elsewhere on the board
D9: J10.1, U$5.37 (PF6(ADC6)); also elsewhere on the board
D10: J12.1, U$5.18 (PD0(SCL)); also elsewhere on the board
D11: J13.1, U$5.19 (PD1(SDA)); also elsewhere on the board
D25: U$5.26 (PD6(ADC9))
D+: R4.1, U$5.4 (D+)
D-: R5.1, U$5.3 (D-)
GND: C2.1, C3.1, C4.1, C5.1, C6.1, C7.1, C8.1, J4.1, J14.1, J15.GND, J16.1 (-), LED4.C, LED5.C, LED6.C, LED7.C, LED8.C, LED9.C, R2.1, S1.3, S2.1, S2.2 (1), U1.2 (VSS), U2.2 (GND), U$5.5 (UGND), U$5.15 (GND), U$5.23 (GND), U$5.33 (PE2/!HWB), U$5.35 (GND), U$5.43 (GND), U$6.4 (C), Y1.2; also elsewhere on the board
MISO: TP1.P$1, U$5.11 (PB3(MISO))
MOSI: TP2.P$1, U$5.10 (PB2(MOSI))
unnamed: LED2.C, R6.1
unnamed: S1.2, U2.3 (EN)
unnamed: LED1.A, R1.1
unnamed: LED1.C, U1.1 (STAT)
unnamed: U$5.17 (XTAL1), Y1.1
unnamed: R2.2, U1.5 (PROG)
unnamed: U$5.16 (XTAL2), Y1.3
unnamed: R16.1, U$6.2 (GRN)
unnamed: LED7.A, R11.1
unnamed: LED6.A, R10.1
unnamed: LED5.A, R9.1
unnamed: LED8.A, R12.1
unnamed: LED9.A, R13.1
unnamed: R15.1, U$6.3 (BLU)
unnamed: R14.1, U$6.1 (RED)
unnamed: LED4.A, R8.1
unnamed: J15.D-, R5.2
unnamed: J15.D+, R4.2
unnamed: LED3.C, R7.1
RESET: R3.2, S2.3 (2), S2.4 (2), TP4.P$1, U$5.13 (!RESET)
RGB_B: R15.2, U$5.32 (PC7)
RGB_G: R16.2, U$5.31 (PC6)
RGB_R: R14.2, U$5.30 (PB6(ADC13))
RX_LED: R6.2, U$5.8 (PB0(SS))
SCK: TP3.P$1, U$5.9 (PB1(SCK))
TX_LED: R7.2, U$5.22 (PD5)
VCC_1: C7.2, D1.C, J15.VBUS, R1.2, S1.1, U1.4 (VIN), U2.1 (IN), U$5.7 (VBUS)
V_BATT: C8.2, D1.A, J16.2 (+), U1.3 (VBAT)

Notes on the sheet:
32u4 BYPASS
MIC5219 BYPASS
Marshall Taylor
v35
LilyPad concept and shapes by: L. Buechly and N. Seidle
Charge Circuit Bypass
Battery Input Bypass
Petal 2 -- LUX
Petal 3 -- BZR
Petal 4 -- BTN
Petal 5 LED Y / ANA
Petal 6 -- LED R / PWM
Petal 7 -- LED G / PWM
Petal 8 -- LED B / PWM
Petal 9 -- ANA
Petal 10 -- SCL / PWM
Petal 11 -- SDA
Petal "+"
Petal "-"
LilyPad Prototyping Board
Microcontroller
Battery Charger and Regulator

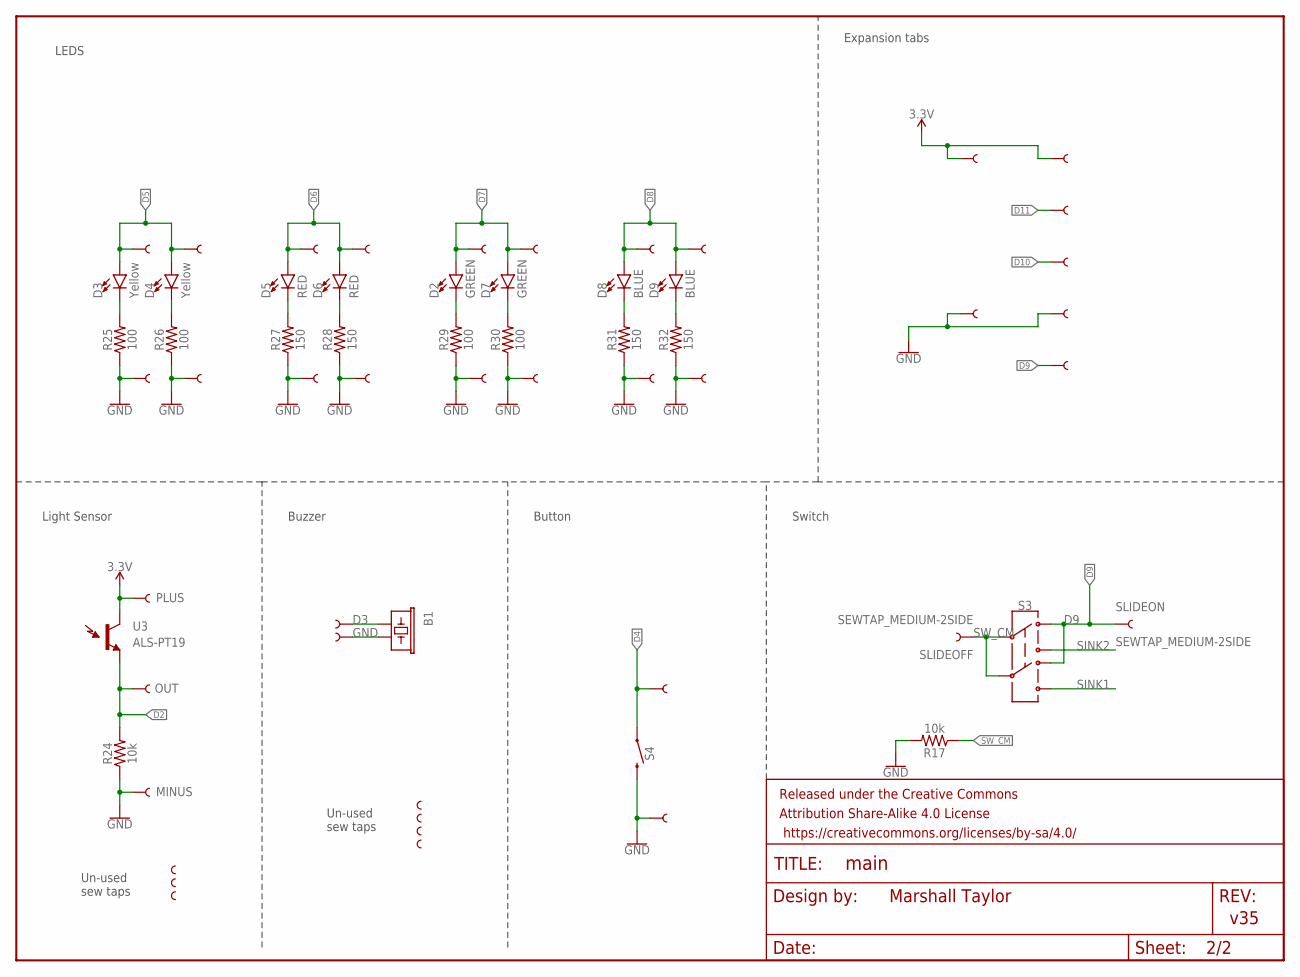
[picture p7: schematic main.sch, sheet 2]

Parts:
B1: Buzzer; BUZZER-CCV
D2, D7: GREEN; LED-1206
D3, D4: Yellow; LED-1206
D5, D6: RED; LED-1206
D8, D9: BLUE; LED-1206
FRAME2: FRAME-LETTERNO_PACKAGE; DUMMY
JP1, JP4, JP5, JP6, JP7, JP8, JP9, JP10, JP20, JP21, JP22, JP23, JP24, JP25, JP26, JP27: SEWTAP_SMALL-2SIDE; PETAL-SMALL-2SIDE
JP12, JP13: SEWTAP_MEDIUM-2SIDE; PETAL-MEDIUM-2SIDE
R17, R24: 10k; 0603
R25, R26, R29, R30: 100; 0603
R27, R28, R31, R32: 150; 0603
S3: SWITCH-DPDT-SMD-AYZ0202; SWITCH_DPDT_SMD_AYZ0202
S4: MOMENTARY-SWITCH-SPST-SMD-4.6X2.8MM; TACTILE_SWITCH_SMD_4.6X2.8MM
SEWTAPLS+: PLUS; PETAL-SMALL-2SIDE
SEWTAPLS-: MINUS; PETAL-SMALL-2SIDE
SEWTAPLSOUT: OUT; PETAL-SMALL-2SIDE
SLIDEOFF: SEWTAP_MEDIUM-2SIDE; PETAL-MEDIUM-2SIDE
SLIDEON: SEWTAP_MEDIUM-2SIDE; PETAL-MEDIUM-2SIDE
ST1, ST2, ST3: SEWTAP-NOHOLE_SM_NH; PETAL-SMALL-NOHOLE
U3: ALS-PT19
U$35, U$36, U$37, U$40: SEWTAP-NOHOLE_SM_NH; PETAL-SMALL-NOHOLE
U$38, U$39: SEWTAP_SMALL; PETAL-SMALL
U$41, U$42, U$51/SDA, U$52/SCL, U$52/SCL1, U$53, U$54: GATOR_HOLE_PAIR; GATOR_HOLES

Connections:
3.3V: SEWTAPLS+.1, U3.C (C1), U$41.P$1, U$41.P$2, U$42.P$1, U$42.P$2; also elsewhere on the board
D2: R24.2, SEWTAPLSOUT.1, U3.E (E1); also elsewhere on the board
D3: B1.+ (1), U$39.1; also elsewhere on the board
D4: JP12.1, S4.1, S4.2 (1); also elsewhere on the board
D5: D3.A, D4.A, JP20.1, JP22.1; also elsewhere on the board
D6: D5.A, D6.A, JP24.1, JP26.1; also elsewhere on the board
D7: D2.A, D7.A, JP7.1, JP8.1; also elsewhere on the board
D8: D8.A, D9.A, JP9.1, JP10.1; also elsewhere on the board
D9: S3.1, S3.4, SLIDEON.1, U$52/SCL1.P$1, U$52/SCL1.P$2; also elsewhere on the board
D10: U$52/SCL.P$1, U$52/SCL.P$2; also elsewhere on the board
D11: U$51/SDA.P$1, U$51/SDA.P$2; also elsewhere on the board
GND: B1.- (2), JP1.1, JP4.1, JP5.1, JP6.1, JP13.1, JP21.1, JP23.1, JP25.1, JP27.1, R17.2, R24.1, R25.1, R26.1, R27.1, R28.1, R29.1, R30.1, R31.1, R32.1, S4.3 (2), S4.4 (2), SEWTAPLS-.1, U$38.1, U$53.P$1, U$53.P$2, U$54.P$1, U$54.P$2; also elsewhere on the board
unnamed: D3.C, R25.2
unnamed: D4.C, R26.2
unnamed: D5.C, R27.2
unnamed: D6.C, R28.2
SINK1: S3.6
SINK2: S3.3
SW_CM: R17.1, S3.2, S3.5, SLIDEOFF.1
X003: D2.C, R29.2
X004: D7.C, R30.2
X005: D8.C, R31.2
X006: D9.C, R32.2

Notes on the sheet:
Un-used sew taps
Light Sensor
Button
LEDS
Expansion tabs
Buzzer
Marshall Taylor
v35
Switch

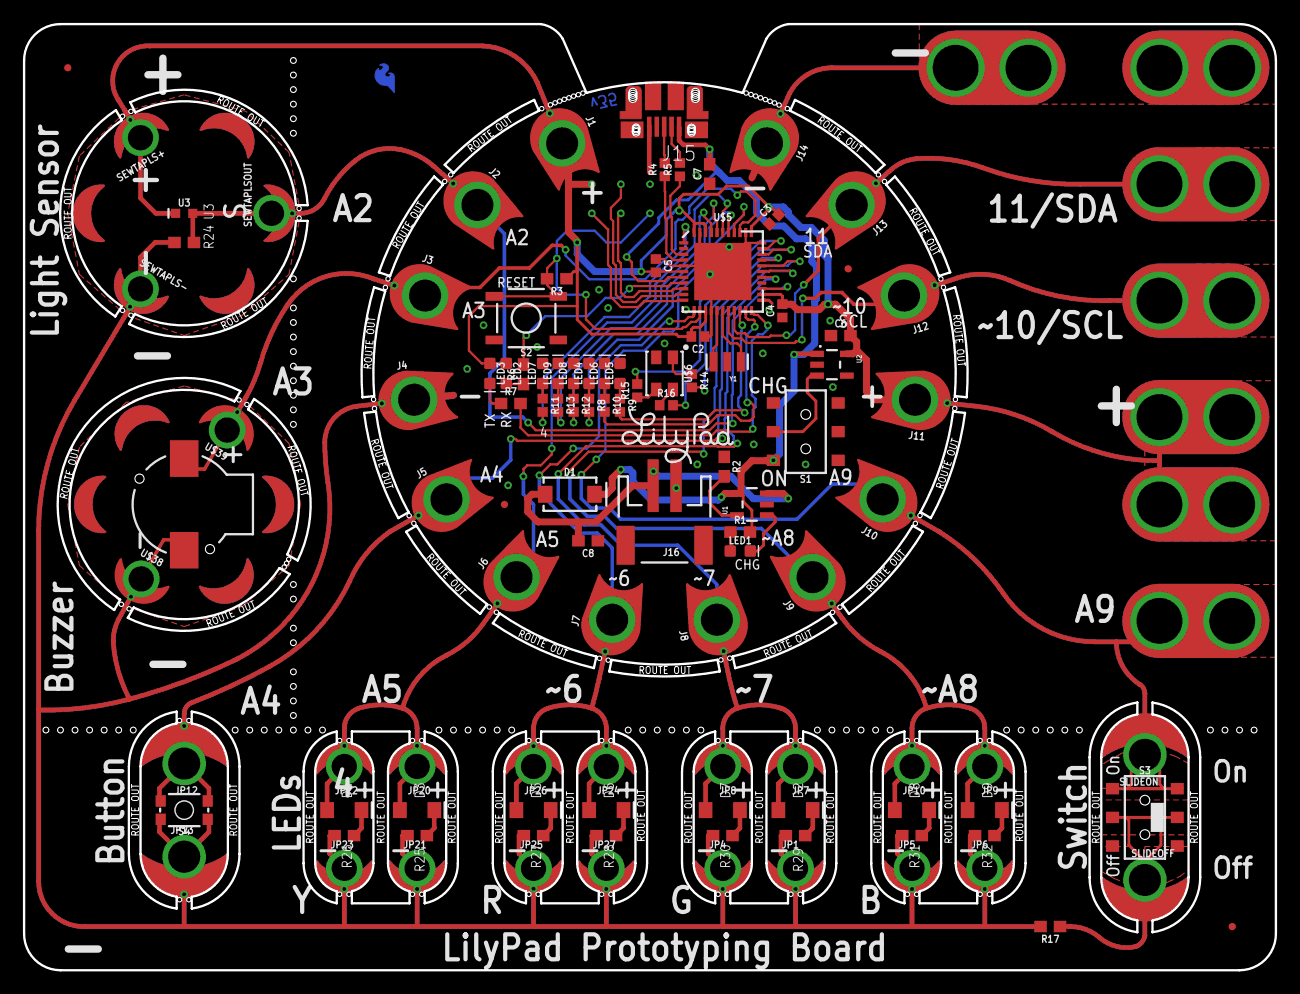
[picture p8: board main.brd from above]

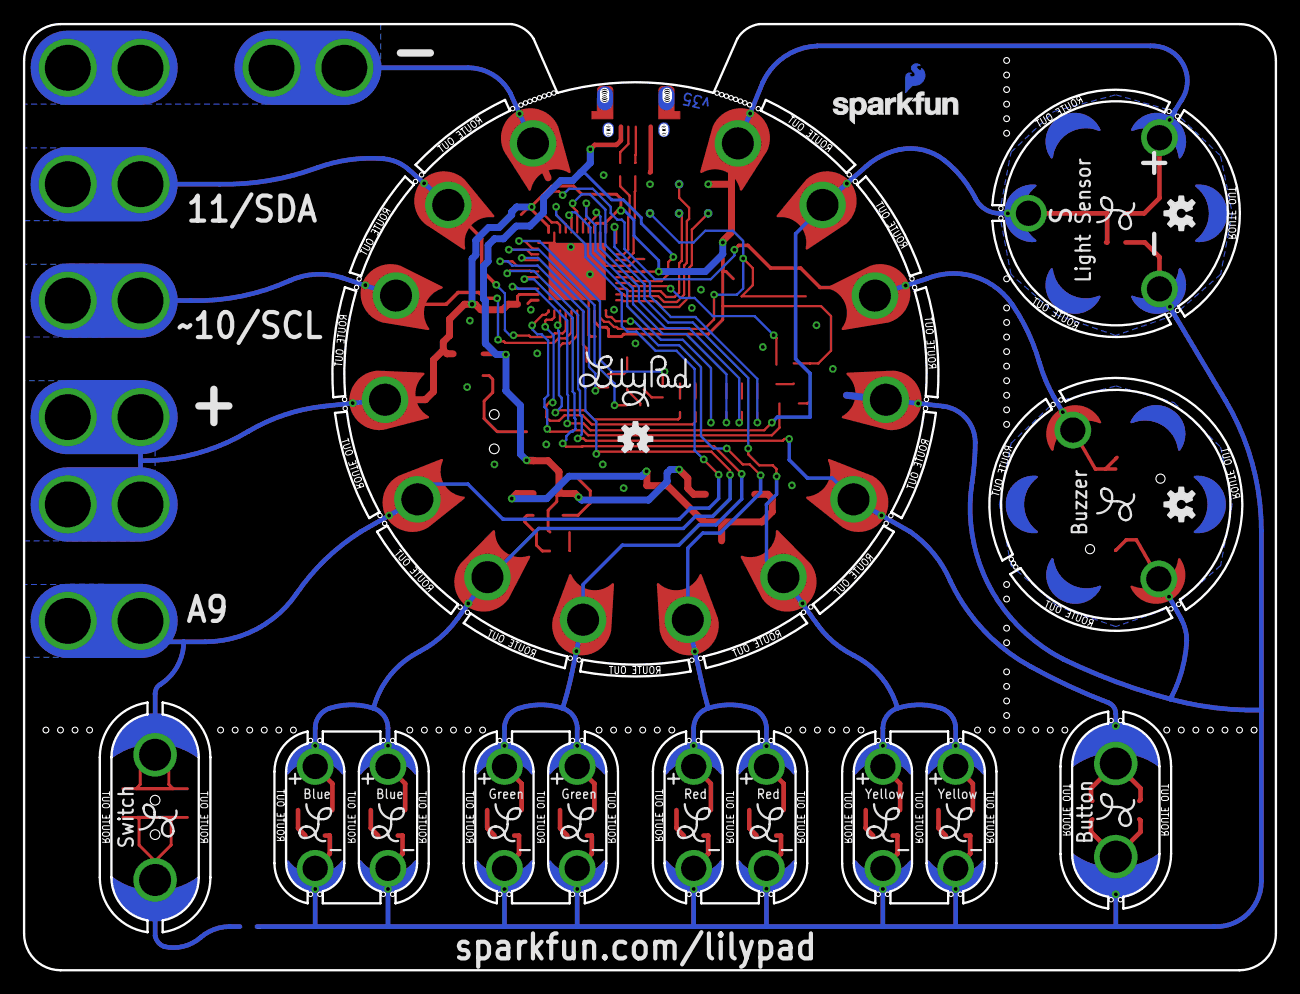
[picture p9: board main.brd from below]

Board: 2 copper layers, 109.2 x 82.5 mm, 193 parts (22 on the bottom side), 59 nets.

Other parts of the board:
L001, L002, L003, L004: LOGO-L
U$3, U$9, U$11, U$15, U$17, U$19, U$21, U$23, U$25, U$27, U$29, U$31, U$33, U$34: PETAL_PAD_OFF
U$7, U$8, U$10, U$12, U$16, U$18, U$20, U$22, U$24, U$26, U$28, U$30, U$32: PETAL_SPACE_OFF
U$45, U$46, U$48, U$49, U$50: LOGO-L
U$51, U$52, U$55, U$56, U$57, U$58, U$59, U$60, U$61, U$62, U$63, U$64, U$65, U$66, U$67, U$68, U$69, U$70, U$71: ROUTE_TICKS

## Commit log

2017-06-08 Center (mcu) board complete
    [mcu_sub.brd, mcu_sub.sch]
2017-06-13 v35 ready for initial review
    [13533-LilyMini_Protosnap-panel.v10.brd, LilyMini_Protosnap.brd, LilyMini_Protosnap.sch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]
2017-06-14 Almost ready for review. Art has been finalized
    [LilyPad_Slide_Switch.brd, LilyPad_Slide_Switch.sch, main.brd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]
2017-06-14 Ready for review
    [LilyPad_Prototyping_Board.brd, LilyPad_Prototyping_Board.sch, mcu_sub.brd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]
2017-06-14 Added part number to RGB led
    [LilyPad_Prototyping_Board.brd, LilyPad_Prototyping_Board.sch]
2017-06-14 Tweaked a couple resistor values
    [LilyPad_Prototyping_Board.brd, LilyPad_Prototyping_Board.sch]
2017-06-14 Fixed some stop/lilypad tab errors
    [LilyPad_Prototyping_Board.brd, LilyPad_Prototyping_Board.sch]
2017-06-15 Addressed DFM errors
    [LilyPad_Prototyping_Board.brd, LilyPad_Prototyping_Board.sch, Lilypad_Arduino_USB-Panel-v12.brd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]
2017-06-15 Added extra test points
    [LilyPad_Prototyping_Board.brd, LilyPad_Prototyping_Board.sch]
2017-06-16 Moved lilypad logo to dodge connector, created v01 gerbers
    [LilyPad_Prototyping_Board.GBL, LilyPad_Prototyping_Board.GBO, LilyPad_Prototyping_Board.GBS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]
2017-06-20 Adjusted routes, drills, and USB connector for PCB fab house requirements, incremented design to v03
    [LilyPad_Prototyping_Board.GBL, LilyPad_Prototyping_Board.GBO, LilyPad_Prototyping_Board.GBS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]
2017-08-15 Implemented most physical changes from proto 1
    [LilyPad_Prototyping_Board.brd, LilyPad_Prototyping_Board.sch]
2017-08-16 More proto changes in
    [LilyPad_Prototyping_Board.brd, LilyPad_Prototyping_Board.sch]
2017-08-16 Added pth/npth notes
    [LilyPad_Prototyping_Board.brd]
2017-08-17 Imported new silk
    Replaced name and major labeling with polygons derived from Trebuchet
    font (LilyPad standard). Polarity and internal labeling left in Eagle
    vector font.
    [LilyPad_Prototyping_Board.brd, LilyPad_Prototyping_Board.sch]
2017-08-21 Added changes from reds review
    [LilyPad_ProtoSnap_Plus.brd, LilyPad_ProtoSnap_Plus.sch, pin_mapping.ods]
2017-08-21 Ran engineering checklist
    [LilyPad_ProtoSnap_Plus.brd, LilyPad_ProtoSnap_Plus.sch]
2017-08-22 Updated reds QC check
    [LilyPad_ProtoSnap_Plus.brd, LilyPad_ProtoSnap_Plus.sch]
2017-08-22 Removed d2 90
    [LilyPad_ProtoSnap_Plus.brd]
2017-08-23 Fixed bad holes, mask issue
    [LilyPad_ProtoSnap_Plus.brd]
2017-09-25 Fixed spelling error
    [LilyPad_ProtoSnap_Plus.brd, LilyPad_ProtoSnap_Plus.sch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]
2017-09-26 Updated documentation in preparation for release
    [13533-LilyMini_Protosnap-panel.v10.brd, LilyMini_Protosnap.brd, LilyMini_Protosnap.sch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]
2017-10-02 Changed bargraph resistors to 470 ohm
    To reduce brightness of white LED bargraph, changed R8-R13 inclusive
    from 22 ohm to 470 ohm 0402 RES-13829 (new part)
    [LilyPad_ProtoSnap_Plus.brd, LilyPad_ProtoSnap_Plus.sch]
2018-01-12 Testing driver

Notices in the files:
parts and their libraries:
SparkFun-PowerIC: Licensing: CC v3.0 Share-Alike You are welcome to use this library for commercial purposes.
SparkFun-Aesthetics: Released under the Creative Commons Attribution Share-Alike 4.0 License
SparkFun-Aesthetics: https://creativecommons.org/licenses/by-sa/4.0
